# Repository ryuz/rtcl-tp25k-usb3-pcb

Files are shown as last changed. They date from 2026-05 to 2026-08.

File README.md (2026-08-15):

English version: [README_en.md](README_en.md)

# Tang Primer 25K 用 FT601 + MIPIコネクタ オリジナルベース基板

## 概要

Sipeed社の [Tang Primer 25K](https://wiki.sipeed.com/hardware/en/tang/tang-primer-25k/primer-25k.html) に搭載されている GW5A-LV25MG121 には MIPI D-PHY インターフェースが搭載されており、SoM までは配線が来ているようですが、残念ながら標準の Dock base board ではこのラインが未接続のままになっており、利用することができません。

本プロジェクトでは、MIPI D-PHY ラインを活用できるように 0.5mm ピッチ 22pin のコネクタに引き出したうえで、画像データなどを PC と交換できるように FT601 で USB3.0 接続できるオリジナルベース基板の設計データを提供します。

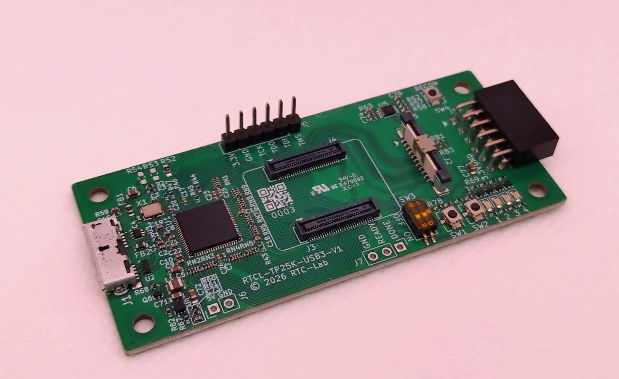
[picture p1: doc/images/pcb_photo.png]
pcb_photo


Tang Primer 25K の SoMボード でもともと使われていなかった MIPI ピンを利用するようにしていますが、特に MIPI を活用しなくとも、USB3.0 で FPGA を使えるようにしたボードとも言えますので、今まで FPGA と PC との接続で UART 程度で止まっていた人に本格的な FPGA 活用への第一歩として利用いただければ幸いです。

また、当方では試しておりませんが、GW5A-LV25MG121 の MIPI D-PHY は双方向ですので、MIPI-DSI など、表示系の実験にも利用できる可能性があります。

## スペック

主な実装内容は以下です。

- Tang-Primer25K-Core 取り付け用コネクタ
- FT601 による USB3.0 接続
- 4レーン MIPI コネクタ (22pin)
- PMOD コネクタ一個
- LED 4個
- プッシュスイッチ2個
- 2極ディップスイッチ
- JTAG 接続用 6pin ヘッダ

JTAG は外部に別途ダウンロードケーブルが必要ですが、[openFPGAloader](https://github.com/trabucayre/openFPGALoader)などを利用する場合は幅広いダウンロードケーブルが利用可能です。

また FT232HL などを利用する場合は、GOWIN EDA の GAO などを使ったデバッグも可能です。

## システムイメージ

### カメラ接続

[Raspberry PI V2 Camera](https://www.raspberrypi.com/documentation/accessories/camera.html) の接続例と、当方作の[RTCL-P3S7-MIPI](https://rtc-lab.com/products/rtcl-cam-p3s7-mipi/)の接続例です。

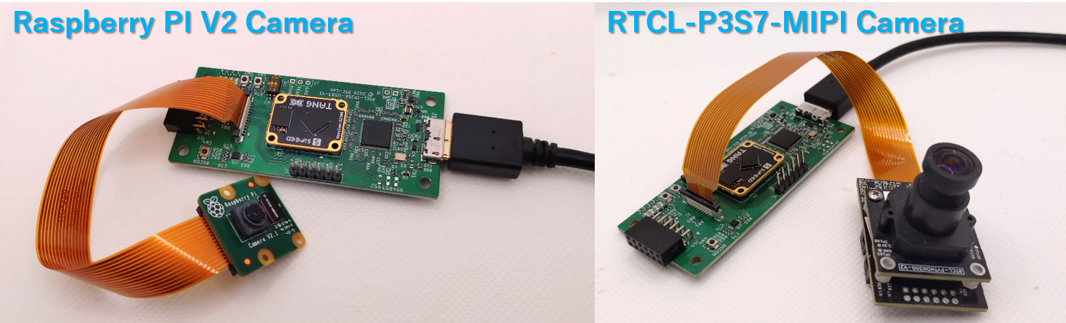
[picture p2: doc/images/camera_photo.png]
カメラ接続イメージ


### JTAG接続

Digilent社の [JTAG-HS２](https://digilent.com/reference/programmers/jtag-hs2/start) の接続例と、秋月電子の[FT232HL ハイスピードUSBシリアル変換モジュール](https://akizukidenshi.com/catalog/g/g106503/) の接続例です。

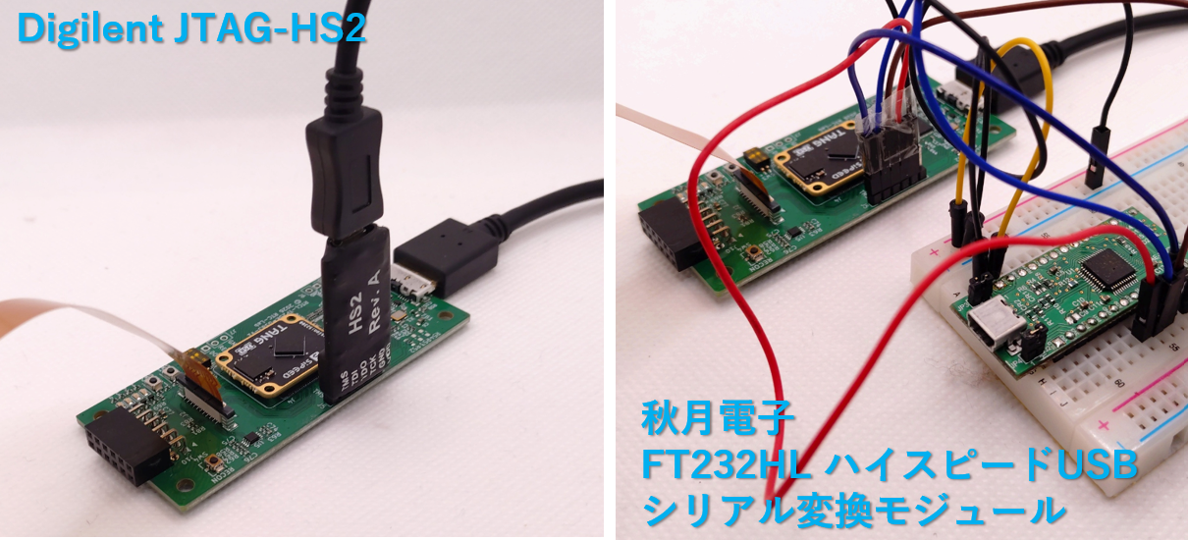
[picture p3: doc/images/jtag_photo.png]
JTAG接続イメージ


## 設計データ

### 回路図

回路図は以下です。

- [rtcl-tp25k-usb3_v2.pdf](rtcl-tp25k-usb3_v2.pdf)

### KiCAD 設計データ

rtcl-tp25k-usb3 ディレクトリ以下に KiCAD 10.0 で設計したデータを格納しています。

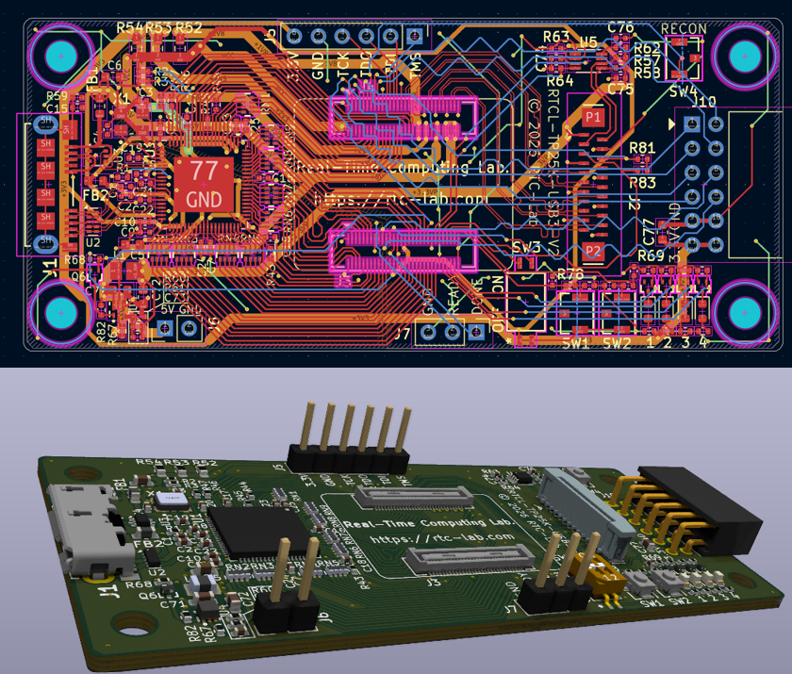
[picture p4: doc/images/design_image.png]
design_image


JLCPCB の `JLC04161H-3313` で製造する想定で設計しています。

### ソフトウェア

下記にて開発中です。

https://github.com/ryuz/rtcl-designs/tree/main/projects/rtcl_tp25k_usb3

## 基板販売

当方で製造したものを[BOOTH](https://rtc-lab.booth.pm/) 及び [BASE](https://rtcl.base.shop/) にて販売中です。

詳細は下記をご覧ください。

https://rtc-lab.com/products/rtcl-design-rtcl_tp25k_usb3/

## 免責事項

本設計データは、研究開発用の試作実験に供するものであり、利用に際して発生した如何なる損害も作者は補償いたしませんので予めご了承ください。

また設計データについてもなんら品質を保証するものではありません。

## ライセンス(License)

本設計データは、[クリエイティブ・コモンズ 表示-非営利 4.0 国際 ライセンス(CC BY-NC 4.0)](https://creativecommons.org/licenses/by-nc/4.0/deed.ja)の下で提供されています。

製造した本基板の無断での販売や配布を行わない限りは、趣味や研究開発用途でご自由にお使いいただく事が出来ます。

また、商用に製造販売を希望される場合は、別途ライセンス契約を作者までご相談ください。[お問い合わせフォーム](https://rtc-lab.com/contact/)などからお問い合わせ頂けます。

## 作者情報

渕上 竜司(Ryuji Fuchikami)
[リアルタイムコンピューティング研究所](https://rtc-lab.com/)

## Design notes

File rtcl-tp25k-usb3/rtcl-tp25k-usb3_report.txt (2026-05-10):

PCB 統計レポート
=====================
- 日付: 2026/05/10 14:33:20
- プロジェクト: rtcl-tp25k-usb3
- 基板名: rtcl-tp25k-usb3

基板
-----
- 幅: 80.0000 mm
- 高さ: 35.0000 mm
- 面積: 2800.00 mm²
- 表面導体面積: 554.94 mm²
- 裏面導体面積: 82.423 mm²
- 最小配線クリアランス: 0.1270 mm
- 最小配線幅: 0.1000 mm
- 最小ドリル直径: 0.3000 mm
- 基板スタックアップ厚さ: 1.6000 mm

- 表面フットプリント面積: 948.035 mm²
- 裏面フットプリント面積: 110.137 mm²
- 表面コンポーネント密度: 33.86 %
- 裏面コンポーネント密度: 3.93 %
パッド
----
- スルーホール: 18
- SMD: 470
- コネクタ: 0
- NPTH: 6
- 端面スルーホール: 0
- プレスフィット: 0

ビア
----
- 貫通ビア: 5
- ブラインド ビア: 0
- ベリード ビア: 0
- マイクロビア: 0

コンポーネント
----------

| | 表面 | 裏面 | 合計 |
|---|----|----|----|
|THT:  |  2 |  0 |  2 |
|SMD:  | 76 |  0 | 76 |
|不特定:  |  4 |  0 |  4 |
|合計: | 82 |  0 | 82 |

ドリル穴
-----------

| カウント | 形状 | X サイズ | Y サイズ |  メッキ | ビア/パッド | 開始レイヤー | 終了レイヤー |
|---|---|---|---|---|---|---|---|
| 18 | ラウンド | 1.0000 mm | 1.0000 mm |  PTH | パッド | F.Cu | B.Cu |
| 5 | ラウンド | 0.3000 mm | 0.3000 mm |  PTH | ビア | F.Cu | B.Cu |
| 4 | ラウンド | 3.2000 mm | 3.2000 mm | NPTH | パッド | F.Cu | B.Cu |
| 2 | スロット | 1.5001 mm | 0.8349 mm | NPTH | パッド | F.Cu | B.Cu |

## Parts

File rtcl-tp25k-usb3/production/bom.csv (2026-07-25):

Designator | Footprint | Quantity | Value | LCSC Part #
C1, C10, C11, C12, C15, C16, C17, C18, C19, C2, C20, C21, C22, C23, C24, C25, C7, C74, C75, C76, C8, C9 | 0402 | 22 | 0.1uF
C3, C4 | 0402 | 2 | 18pF
C5, C6, C71, C72, C77 | 0603 | 5 | 4.7uF
C73 | 0402 | 1 | 120pF | C40059
FB1, FB2 | 0603 | 2 | BLM18SG121TN1 | C113030
J1 | ZX360DB10P30 | 1 | ZX360D-B-10P(30) | C598201
J10 | PMOD_02x06_2.54mm | 1 | PMOD | C2897426
J2 | AFC11-S22ICA-00 | 1 | MIPI_22pin | C5248019
J3, J4 | CONN_DF40C-60DS_HIR | 2 | DF40C(2.0)-60DS-0.4V(51) | C3646124
J5 | PinHeader_1x06_P2.54mm_Vertical | 1 | JTAG | C6332199
J6 | PinHeader_1x02_P2.54mm_Vertical | 1 | Conn_01x02
J7 | PinHeader_1x03_P2.54mm_Vertical | 1 | Conn_01x03
L1 | INDC2016X100N | 1 | TFM201610ALM-R47MTAA | C501954
LED1, LED2, LED3, LED4 | 0603 | 4 | 150060VS55040 | C6390388
Q2, Q3, Q4, Q5, Q6 | SOT_34NT1G_ONS | 5 | NTK3134NT1G | C97777
R1 | 0402 | 1 | 1.6k_1%
R2, R3, R68, R69, R72, R74, R76, R77, R78, R79, R80, R81, R82, R83 | 0402 | 14 | 4.7k
R52 | 0603 | 1 | 0_1608 | C15402
R53, R54 | 0603 | 2 | <DNP>_R_1608
R57, R58, R63, R64 | 0402 | 4 | 2.2k
R59 | 0402 | 1 | 1M
R60 | 0402 | 1 | 22.6k_1%
R61 | 0402 | 1 | 100k_1%
R62 | 0402 | 1 | 200k
R67 | 0402 | 1 | 100k
R70, R71, R73, R75 | 0402 | 4 | 100
SW1, SW2, SW4 | B3U-1100P | 3 | B3U-1100P | C6467298
SW3 | 218-2LP_CTS | 1 | 218-2LPSTR | C2961921
U1 | QFN-76-1EP_9x9mm_P0.4mm_EP5.81x6.31mm | 1 | FT601Q | C1550513
U2 | USON-10_2.5x1.0mm_P0.5mm | 1 | TPD4E05U06DQA | C138714
U3 | SOT-666 | 1 | USBLC6-2P6 | C15999
U4 | DMQ0006A | 1 | TPS62826DMQR | C2073319
U5 | VSSOP-8_2.3x2mm_P0.5mm | 1 | PCA9306DCUR | C33196
X1 | XTAL_ABM8-30.000MHz-D1X-T | 1 | ABM8-30.000MHZ-D1X-T | C1986781

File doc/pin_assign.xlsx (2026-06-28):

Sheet: Sheet1
RTL | pin | SoMネット名 | FT601ネット名
ft601_clk | K5 | K5_IOT63B | FT601_CLK
ft601_txe_n | G2 | G2_IOR24A_40P | FT601_TXE
ft601_rxf_n | K4 | K4_IOR22B_40P | FT601_RXF
ft601_siwu_n | J4 | J4_IOR22A_40P | FT601_SIWU
ft601_wr_n | K2 | K2_IOR20B_40P | FT601_WR
ft601_rd_n | K1 | K1_IOR20A_40P | FT601_RD
ft601_oe_n | L1 | L1_IOR18B_40P | FT601_OE
ft601_gpio[0] | H1 | G1_IOR24B_40P | FT601_GPIO0
ft601_gpio[1] | H2 | L4_IOR31A_40P | FT601_GPIO1
ft601_be[0] | J1 | J1_IOR33A_40P | FT601_BE0
ft601_be[1] | L3 | L3_IOR31B_40P | FT601_BE1
ft601_be[2] | L4 | L4_IOR31A_40P | FT601_BE2
ft601_be[3] | G1 | G1_IOR24B_40P | FT601_BE3
ft601_data[0] | L11 | L11_IOT11B | FT601_D0
ft601_data[1] | K11 | K11_IOT11A | FT601_D1
ft601_data[2] | K10 | K10_IOT15B_40P | FT601_D2
ft601_data[3] | L10 | L10_IOT15A_40P | FT601_D3
ft601_data[4] | L8 | L8_IOT19B_40P | FT601_D4
ft601_data[5] | L7 | L7_IOT19A_40P | FT601_D5
ft601_data[6] | J7 | J7_IOT21B_40P | FT601_D6
ft601_data[7] | K7 | K7_IOT21A_40P | FT601_D7
ft601_data[8] | K6 | K6_IOT23B_USB_N | FT601_D8
ft601_data[9] | L6 | L6_IOT23A_USB_P | FT601_D9
ft601_data[10] | G5 | G5_IOT72B | FT601_D10
ft601_data[11] | F5 | F5_IOT72A | FT601_D11
ft601_data[12] | G8 | G8_IOT68B | FT601_D12
ft601_data[13] | G7 | G7_IOT68A | FT601_D13
ft601_data[14] | H7 | H7_IOT66B | FT601_D14
ft601_data[15] | H8 | H8_IOT66A | FT601_D15
ft601_data[16] | H5 | H5_IOT61A | FT601_D16
ft601_data[17] | J5 | J5_IOT61B | FT601_D17
ft601_data[18] | L5 | L5_IOT63A | FT601_D18
ft601_data[19] | L9 | L9_IOT31A_40P | FT601_D19
ft601_data[20] | K9 | K9_IOT31B_40P | FT601_D20
ft601_data[21] | J8 | J8_IOT56A_40P | FT601_D21
ft601_data[22] | K8 | K8_IOT56B_40P | FT601_D22
ft601_data[23] | F7 | F7_IOT58A_40P | FT601_D23
ft601_data[24] | F6 | F6_IOT58B_40P | FT601_D24
ft601_data[25] | J11 | J11_IOT1A_40P | FT601_D25
ft601_data[26] | J10 | J10_IOT1B_40P | FT601_D26
ft601_data[27] | H11 | H11_IOT3A_S1 | FT601_D27
ft601_data[28] | H10 | H10_IOT3B_S2 | FT601_D28
ft601_data[29] | G11 | G11_IOT7A | FT601_D29
ft601_data[30] | G4 | G4_IOB89A_40P | FT601_D30
ft601_data[31] | J2 | J2_IOR33B_40P | FT601_D31
ft601_reset_n | L2 | L2_IOR18A_40P | FT601_RESET
ft601_wakeup | H4 | H4_IOB89B_40P | FT601_WAKEUP

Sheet: Sheet2
No. | conn | pin | FPGA | NAME | bank | attr | Voltage | RTL | LOC
1 | J3 | 2 |  | GND | 0
12 | J3 | 24 |  | VCCIO0_1
13 | J3 | 26 |  | VCCIO0_1 |  |  |  |  |  | 1
14 | J3 | 28 |  | GND |  |  |  |  |  | 1
25 | J3 | 50 |  | GND |  |  |  |  |  | 1
30 | J3 | 60 |  | GND
31 | J3 | 1 |  | GND | 0 |  |  |  |  | 1
38 | J3 | 15 |  | GND |  |  |  |  |  | 1
44 | J3 | 27 |  | GND |  |  |  |  |  | 1
45 | J3 | 29 |  | VCCIO6_7 |  |  |  |  |  | 1
46 | J3 | 31 |  | VCCIO6_7 |  |  |  |  |  | 1
53 | J3 | 45 |  | GND |  |  |  |  |  | 1
60 | J3 | 59 |  | GND
61 | J4 | 2 |  | VCCIO2_3
62 | J4 | 4 |  | VCCIO2_3
79 | J4 | 38 |  | 1.8V |  |  |  |  |  | 1
80 | J4 | 40 |  | 1.8V |  |  |  |  |  | 1
81 | J4 | 42 |  | 2.5V |  |  |  |  |  | 1
82 | J4 | 44 |  | 2.5V |  |  |  |  |  | 1
83 | J4 | 46 |  | 3.3V |  |  |  |  |  | 1
84 | J4 | 48 |  | 3.3V |  |  |  |  |  | 1
85 | J4 | 50 |  | 3.3V |  |  |  |  |  | 1
86 | J4 | 52 |  | 5V |  |  |  |  |  | 1
87 | J4 | 54 |  | 5V |  |  |  |  |  | 1
88 | J4 | 56 |  | 5V |  |  |  |  |  | 1
89 | J4 | 58 |  | 5V
90 | J4 | 60 |  | 5V |  |  |  |  |  | 1
91 | J4 | 1 |  | GND |  |  |  |  |  | 1
97 | J4 | 13 | D8 | D8_RECONFIG | 5 |  | 3.3 |  |  | 1
100 | J4 | 19 |  | GND |  |  |  |  |  | 1
105 | J4 | 29 |  | GND
111 | J4 | 41 |  | GND
114 | J4 | 47 |  | GND |  |  |  |  |  | 1
117 | J4 | 53 |  | GND |  |  |  |  |  | 1
120 | J4 | 59 |  | GND |  |  |  |  |  | 1
56 | J3 | 51 | C11 | C11_IOL5A | 6 |  | 1.8 | dip_sw[0] | IO_LOC "dip_sw[0]" C11; | 1
57 | J3 | 53 | C10 | C10_IOL5B | 6 |  | 1.8 | dip_sw[1] | IO_LOC "dip_sw[1]" C10; | 1
73 | J4 | 26 | J1 | J1_IOR33A_40P | 2 | GCLK | 1.8 | ft601_be[0] | IO_LOC "ft601_be[0]" J1; | 1
72 | J4 | 24 | L3 | L3_IOR31B_40P | 2 | GCLK | 1.8 | ft601_be[1] | IO_LOC "ft601_be[1]" L3;
71 | J4 | 22 | L4 | L4_IOR31A_40P | 2 | GCLK | 1.8 | ft601_be[2] | IO_LOC "ft601_be[2]" L4;
70 | J4 | 20 | G1 | G1_IOR24B_40P | 2 |  | 1.8 | ft601_be[3] | IO_LOC "ft601_be[3]" G1; | 1
5 | J3 | 10 | K5 | K5_IOT63B | 0 | GCLK | 1.8 | ft601_clk | IO_LOC "ft601_clk" K5; | 1
24 | J3 | 48 | L11 | L11_IOT11B | 7 |  | 1.8 | ft601_data[0] | IO_LOC "ft601_data[0]" L11;
23 | J3 | 46 | K11 | K11_IOT11A | 7 |  | 1.8 | ft601_data[1] | IO_LOC "ft601_data[1]" K11;
11 | J3 | 22 | G5 | G5_IOT72B | 0 |  | 1.8 | ft601_data[10] | IO_LOC "ft601_data[10]" G5;
10 | J3 | 20 | F5 | F5_IOT72A | 0 |  | 1.8 | ft601_data[11] | IO_LOC "ft601_data[11]" F5;
9 | J3 | 18 | G8 | G8_IOT68B | 0 |  | 1.8 | ft601_data[12] | IO_LOC "ft601_data[12]" G8;
8 | J3 | 16 | G7 | G7_IOT68A | 0 |  | 1.8 | ft601_data[13] | IO_LOC "ft601_data[13]" G7; | 1
7 | J3 | 14 | H7 | H7_IOT66B | 0 |  | 1.8 | ft601_data[14] | IO_LOC "ft601_data[14]" H7; | 1
6 | J3 | 12 | H8 | H8_IOT66A | 0 |  | 1.8 | ft601_data[15] | IO_LOC "ft601_data[15]" H8; | 1
2 | J3 | 4 | H5 | H5_IOT61A | 0 | GCLK | 1.8 | ft601_data[16] | IO_LOC "ft601_data[16]" H5; | 1
3 | J3 | 6 | J5 | J5_IOT61B | 0 | GCLK | 1.8 | ft601_data[17] | IO_LOC "ft601_data[17]" J5; | 1
4 | J3 | 8 | L5 | L5_IOT63A | 0 | GCLK | 1.8 | ft601_data[18] | IO_LOC "ft601_data[18]" L5;
32 | J3 | 3 | L9 | L9_IOT31A_40P | 0 |  | 1.8 | ft601_data[19] | IO_LOC "ft601_data[19]" L9;
22 | J3 | 44 | K10 | K10_IOT15B_40P | 7 |  | 1.8 | ft601_data[2] | IO_LOC "ft601_data[2]" K10;
33 | J3 | 5 | K9 | K9_IOT31B_40P | 0 |  | 1.8 | ft601_data[20] | IO_LOC "ft601_data[20]" K9;
34 | J3 | 7 | J8 | J8_IOT56A_40P | 0 | GCLK | 1.8 | ft601_data[21] | IO_LOC "ft601_data[21]" J8;
35 | J3 | 9 | K8 | K8_IOT56B_40P | 0 | GCLK | 1.8 | ft601_data[22] | IO_LOC "ft601_data[22]" K8;
36 | J3 | 11 | F7 | F7_IOT58A_40P | 0 | GCLK | 1.8 | ft601_data[23] | IO_LOC "ft601_data[23]" F7;
37 | J3 | 13 | F6 | F6_IOT58B_40P |  | GCLK | 1.8 | ft601_data[24] | IO_LOC "ft601_data[24]" F6;
47 | J3 | 33 | J11 | J11_IOT1A_40P | 7 | GCLK | 1.8 | ft601_data[25] | IO_LOC "ft601_data[25]" J11;
48 | J3 | 35 | J10 | J10_IOT1B_40P | 7 | GCLK | 1.8 | ft601_data[26] | IO_LOC "ft601_data[26]" J10;
49 | J3 | 37 | H11 | H11_IOT3A_S1 | 7 | GCLK | 1.8 | ft601_data[27] | IO_LOC "ft601_data[27]" H11;
50 | J3 | 39 | H10 | H10_IOT3B_S2 | 7 | GCLK | 1.8 | ft601_data[28] | IO_LOC "ft601_data[28]" H10; | 1
51 | J3 | 41 | G11 | G11_IOT7A | 7 |  | 1.8 | ft601_data[29] | IO_LOC "ft601_data[29]" G11; | 1
21 | J3 | 42 | L10 | L10_IOT15A_40P | 7 |  | 1.8 | ft601_data[3] | IO_LOC "ft601_data[3]" L10; | 1
75 | J4 | 30 | G4 | G4_IOB89A_40P | 3 | GCLK | 1.8 | ft601_data[30] | IO_LOC "ft601_data[30]" G4; | 1
74 | J4 | 28 | J2 | J2_IOR33B_40P | 2 | GCLK | 1.8 | ft601_data[31] | IO_LOC "ft601_data[31]" J2; | 1
20 | J3 | 40 | L8 | L8_IOT19B_40P | 7 |  | 1.8 | ft601_data[4] | IO_LOC "ft601_data[4]" L8; | 1
19 | J3 | 38 | L7 | L7_IOT19A_40P | 7 |  | 1.8 | ft601_data[5] | IO_LOC "ft601_data[5]" L7; | 1
18 | J3 | 36 | J7 | J7_IOT21B_40P | 7 |  | 1.8 | ft601_data[6] | IO_LOC "ft601_data[6]" J7; | 1
17 | J3 | 34 | K7 | K7_IOT21A_40P | 7 |  | 1.8 | ft601_data[7] | IO_LOC "ft601_data[7]" K7; | 1
16 | J3 | 32 | K6 | K6_IOT23B_USB_N | 7 |  | 1.8 | ft601_data[8] | IO_LOC "ft601_data[8]" K6; | 1
15 | J3 | 30 | L6 | L6_IOT23A_USB_P | 7 |  | 1.8 | ft601_data[9] | IO_LOC "ft601_data[9]" L6; | 1
77 | J4 | 34 | H1 | H1_IOB91A_40P | 3 | GCLK | 1.8 | ft601_gpio[0] | IO_LOC "ft601_gpio[0]" H1; | 1
78 | J4 | 36 | H2 | H2_IOB91B_40P | 3 | GCLK | 1.8 | ft601_gpio[1] | IO_LOC "ft601_gpio[1]" H2; | 1
64 | J4 | 8 | L1 | L1_IOR18B_40P | 2 |  | 1.8 | ft601_oe_n | IO_LOC "ft601_oe_n" L1; | 1
65 | J4 | 10 | K1 | K1_IOR20A_40P | 2 |  | 1.8 | ft601_rd_n | IO_LOC "ft601_rd_n" K1; | 1
63 | J4 | 6 | L2 | L2_IOR18A_40P | 2 |  | 1.8 | ft601_reset_n | IO_LOC "ft601_reset_n" L2; | 1
68 | J4 | 16 | K4 | K4_IOR22B_40P | 2 |  | 1.8 | ft601_rxf_n | IO_LOC "ft601_rxf_n" K4;
67 | J4 | 14 | J4 | J4_IOR22A_40P | 2 |  | 1.8 | ft601_siwu_n | IO_LOC "ft601_siwu_n" J4;
69 | J4 | 18 | G2 | G2_IOR24A_40P | 2 | RPLL | 1.8 | ft601_txe_n | IO_LOC "ft601_txe_n" G2;
76 | J4 | 32 | H4 | H4_IOB89B_40P | 3 | GCLK | 1.8 | ft601_wakeup | IO_LOC "ft601_wakeup" H4;
66 | J4 | 12 | K2 | K2_IOR20B_40P | 2 |  | 1.8 | ft601_wr_n | IO_LOC "ft601_wr_n" K2;
0 |  |  | E2 | IOB12A | 5 |  | 3.3 | in_clk50 | IO_LOC "in_clk50" E2;
101 | J4 | 21 | C1 | C1_JTAG_TCK | 10 |  | 3.3 | JTAG | IO_LOC "JTAG" C1;
102 | J4 | 23 | B1 | B1_JTAG_TMS | 10 |  | 3.3 | JTAG | IO_LOC "JTAG" B1;
103 | J4 | 25 | A2 | A2_JTAG_TDO | 10 |  | 3.3 | JTAG | IO_LOC "JTAG" A2;
104 | J4 | 27 | A3 | A3_JTAG_TDI | 10 |  | 3.3 | JTAG | IO_LOC "JTAG" A3;
29 | J3 | 58 | A10 | A10_IOL14B | 6 |  |  | led[0] | IO_LOC "led[0]" A10;
28 | J3 | 56 | A11 | A11_IOL14A | 6 |  |  | led[1] | IO_LOC "led[1]" A11;
27 | J3 | 54 | E10 | E10_IOL3B | 6 |  |  | led[2] | IO_LOC "led[2]" E10;
26 | J3 | 52 | E11 | E11_IOL3A | 6 |  |  | led[3] | IO_LOC "led[3]" E11; | 1
113 | J4 | 45 | B7 | M0_CK_N |  |  |  | mipi_ck_n | IO_LOC "mipi_ck_n" B7; | 1
112 | J4 | 43 | A7 | M0_CK_P |  |  |  | mipi_ck_p | IO_LOC "mipi_ck_p" A7; | 1
116 | J4 | 51 | B8 | M0_D1_N |  |  |  | mipi_d_n[1] | IO_LOC "mipi_d_n[1]" B8; | 1
119 | J4 | 57 | B9 | M0_D0_N |  |  |  | mipi_d_n[0] | IO_LOC "mipi_d_n[0]" B9;
110 | J4 | 39 | B6 | M0_D2_N |  |  |  | mipi_d_n[2] | IO_LOC "mipi_d_n[2]" B6;
107 | J4 | 33 | B5 | M0_D3_N |  |  |  | mipi_d_n[3] | IO_LOC "mipi_d_n[3]" B5; | 1
115 | J4 | 49 | A8 | M0_D1_P |  |  |  | mipi_d_p[1] | IO_LOC "mipi_d_p[1]" A8; | 1
118 | J4 | 55 | A9 | M0_D0_P |  |  |  | mipi_d_p[0] | IO_LOC "mipi_d_p[0]" A9;
109 | J4 | 37 | A6 | M0_D2_P |  |  |  | mipi_d_p[2] | IO_LOC "mipi_d_p[2]" A6;
106 | J4 | 31 | A5 | M0_D3_P |  |  |  | mipi_d_p[3] | IO_LOC "mipi_d_p[3]" A5;
96 | J4 | 11 | A1 | A1_IOB24A_40P | 5 |  | 3.3 | mipi_gpio[0] | IO_LOC "mipi_gpio[0]" A1;
42 | J3 | 23 | E3 | E3_IOB60A_40P | 4 |  | 3.3 | mipi_gpio[1] | IO_LOC "mipi_gpio[1]" E3;
52 | J3 | 43 | G10 | G10_IOT7B | 7 |  | 1.8 | mipi_pwr_en_n | IO_LOC "mipi_pwr_en_n" G10;
54 | J3 | 47 | D11 | D11_IOL9A | 6 |  | 1.8 | mipi_scl | IO_LOC "mipi_scl" D11;
55 | J3 | 49 | D10 | D10_IOL9B | 6 |  | 1.8 | mipi_sda | IO_LOC "mipi_sda" D10;
94 | J4 | 7 | F2 | F2_IOB26A_40P | 5 | GCLK | 3.3 | pmod[0] | IO_LOC "pmod[0]" F2;
95 | J4 | 9 | F1 | F1_IOB26B_40P | 5 | GCLK | 3.3 | pmod[1] | IO_LOC "pmod[1]" F1;
92 | J4 | 3 | B2 | B2_IOB4A_40P | 5 |  | 3.3 | pmod[2] | IO_LOC "pmod[2]" B2;
93 | J4 | 5 | C2 | C2_IOB4B_40P | 5 |  | 3.3 | pmod[3] | IO_LOC "pmod[3]" C2;
98 | J4 | 15 | E1 | E1_IOB12B_40P | 5 | GCLK | 3.3 | pmod[4] | IO_LOC "pmod[4]" E1;
99 | J4 | 17 | D1 | D1_IOB14B_40P | 5 |  | 3.3 | pmod[5] | IO_LOC "pmod[5]" D1;
40 | J3 | 19 | B3 | B3_IOB56A_UART_RX | 4 |  | 3.3 | pmod[6] | IO_LOC "pmod[6]" B3;
41 | J3 | 21 | C3 | C3_IOB56B_UART_TX | 4 |  | 3.3 | pmod[7] | IO_LOC "pmod[7]" C3;
59 | J3 | 57 | B10 | B10_IOL12B | 6 |  | 1.8 | push_sw[0] | IO_LOC "push_sw[0]" B10;
58 | J3 | 55 | B11 | B11_IOL12A | 6 |  | 1.8 | push_sw[1] | IO_LOC "push_sw[1]" B11;
39 | J3 | 17 | E8 | E8_READY | 4 |  | 3.3 | test[0] | IO_LOC "test[0]" E8;
43 | J3 | 25 | D7 | D7_DONE | 4 |  | 3.3 | test[1] | IO_LOC "test[1]" D7;
108 | J4 | 35 |  | GND

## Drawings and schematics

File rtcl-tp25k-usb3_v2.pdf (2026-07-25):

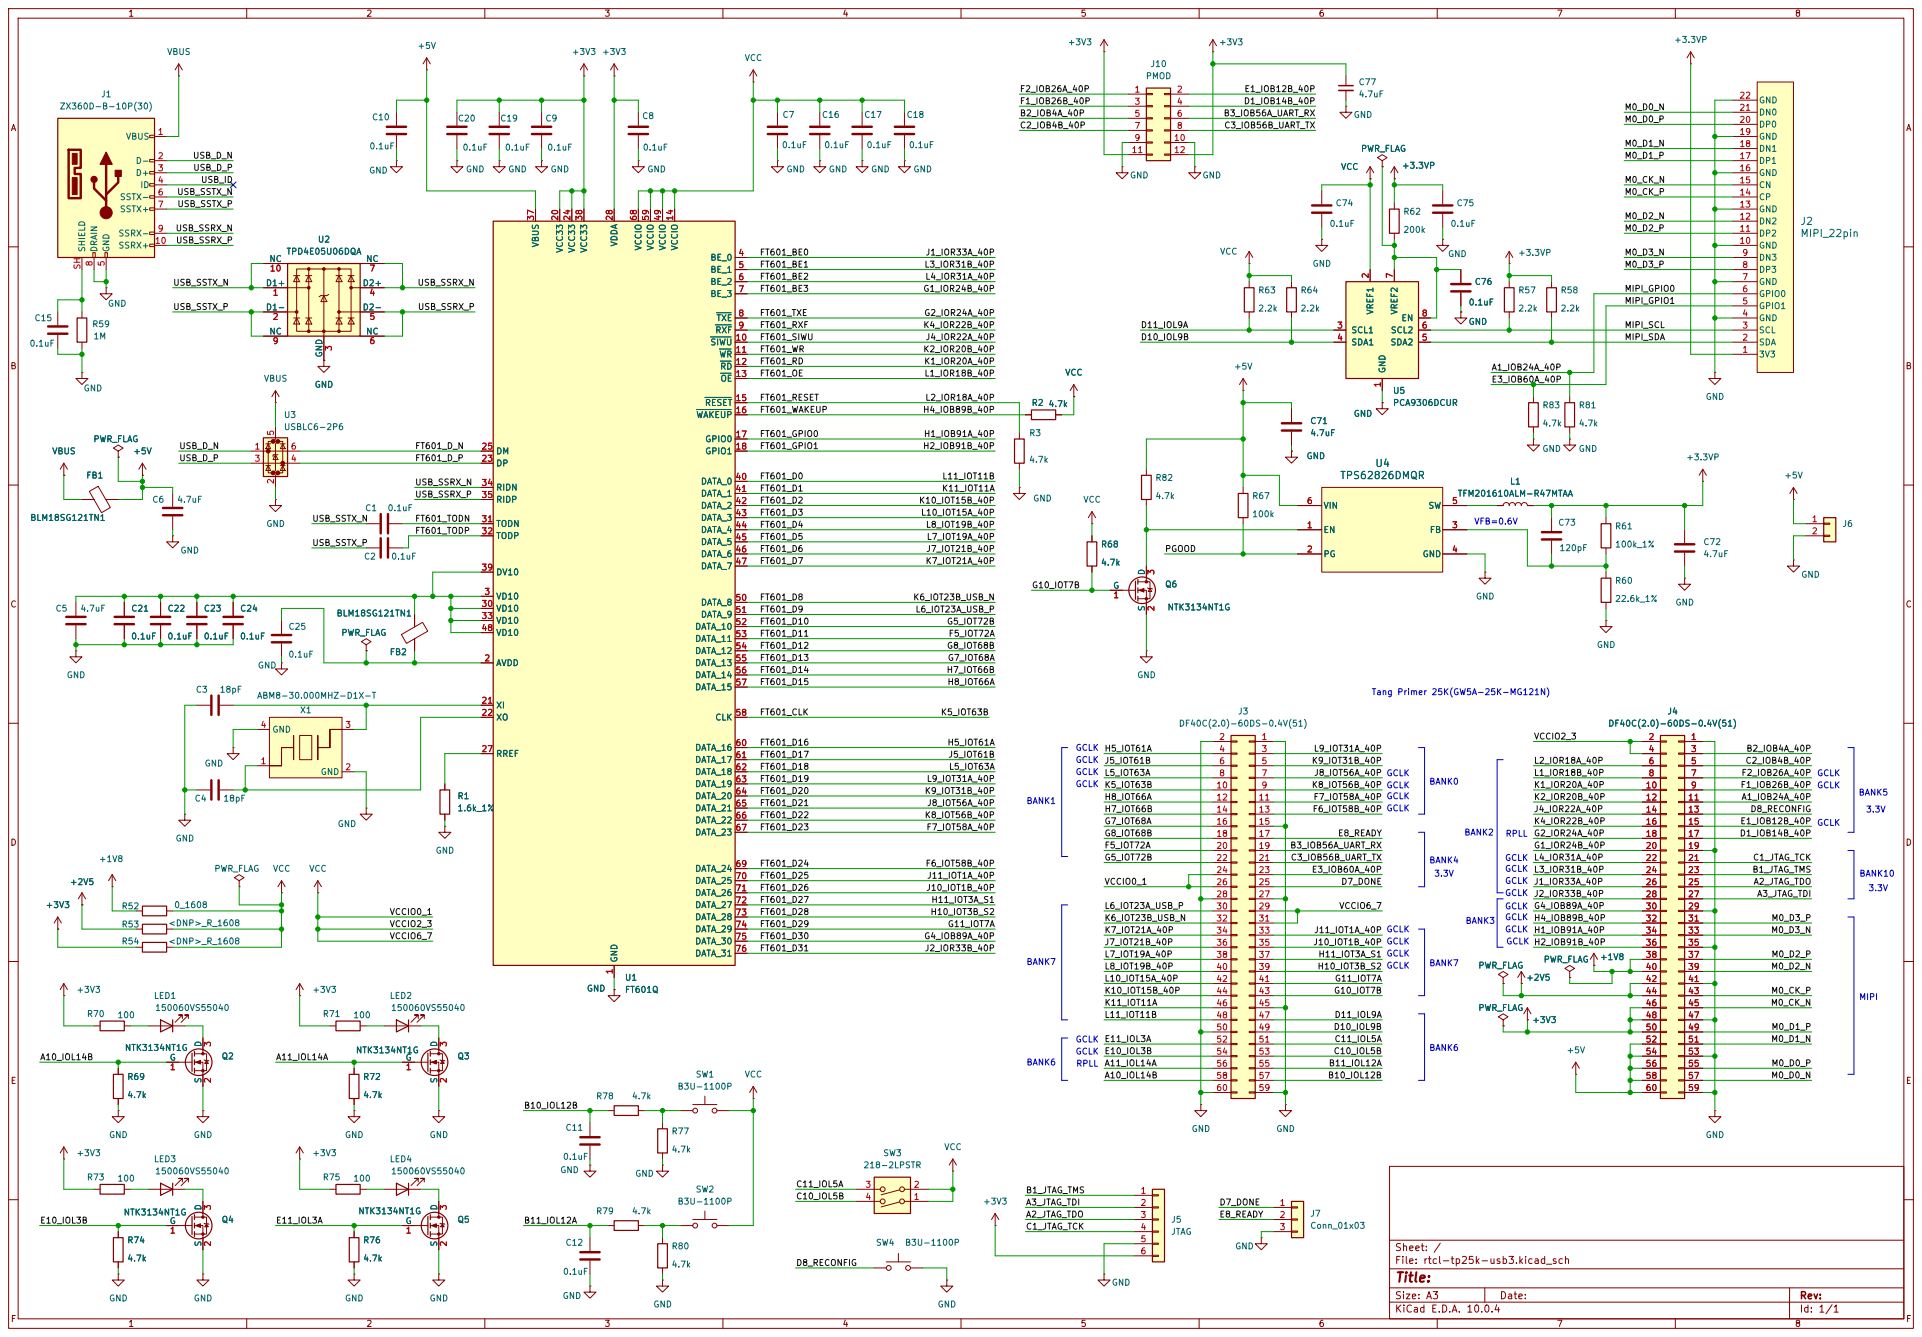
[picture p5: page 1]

D1+ | 6NC 6NC 4 D2-4 D2-
7 NC

Size: A3 | Rev:
KiCad E.D.A. 10.0.4 | Id: 1/1 | F Date:

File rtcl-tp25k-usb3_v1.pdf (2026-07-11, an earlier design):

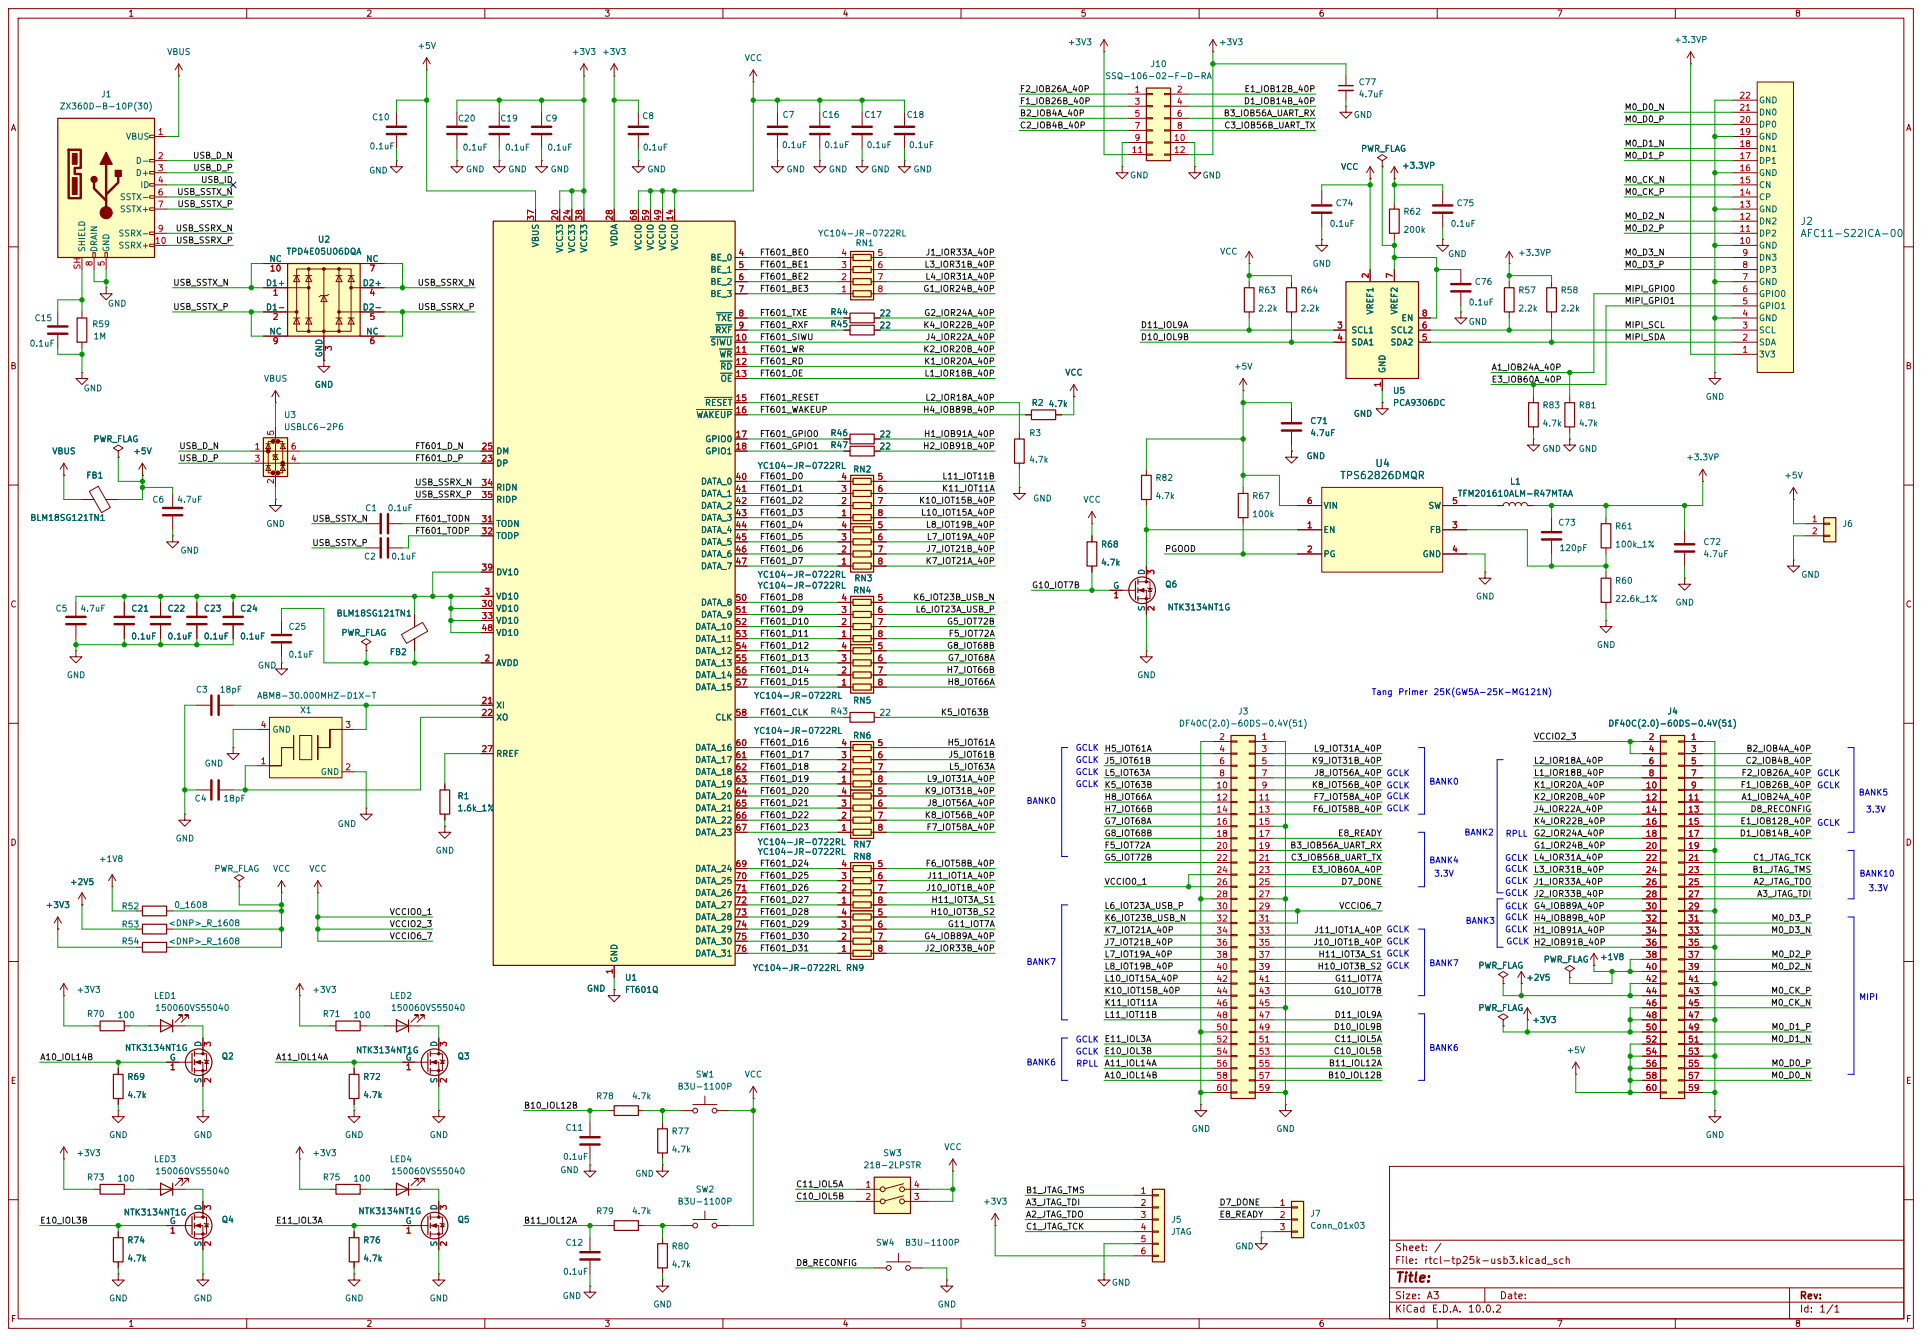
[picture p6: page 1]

ID SSTX+ SSRX+ | 4 GND 7 DRAIN 10 SHIELD SH

FT601_D6 2 2 | 7 7 J7_IOT21B_40P
FT601_D7 1 | K7_IOT21A_40P

FT601_D10 2 2 | 7 7 G5_IOT72B
FT601_D11 1 | F5_IOT72A
FT601_D12 4 4 | 5 5 G8_IOT68B

FT601_D21 3 3 | J3 DF40C(2.0)-60DS-0.4V(51) LED2 6 6 J8_IOT56A_40P

FT601_D17 3 3 | 6 6 J5_IOT61B
FT601_D18 2 2 | 7 7

FT601_D19 | L5_IOT63A K9_IOT31B_40P 8

FT601_D22 2 2 | 7 7 K8_IOT56B_40P

1 1 | 8 F7_IOT58A_40P

FT601_D27 1 | H11_IOT3A_S1 8
FT601_D28 4 4 | 5 5 G11_IOT7A H10_IOT3B_S2

VCCIO2_3 | FT601_D29 3 3 | 6 6

FT601_D30 2 2 | 7 7 G4_IOB89A_40P
FT601_D31 1 1 | 8 J2_IOR33B_40P

Size: A3 | Rev:
KiCad E.D.A. 10.0.2 | Id: 1/1 | F Date:

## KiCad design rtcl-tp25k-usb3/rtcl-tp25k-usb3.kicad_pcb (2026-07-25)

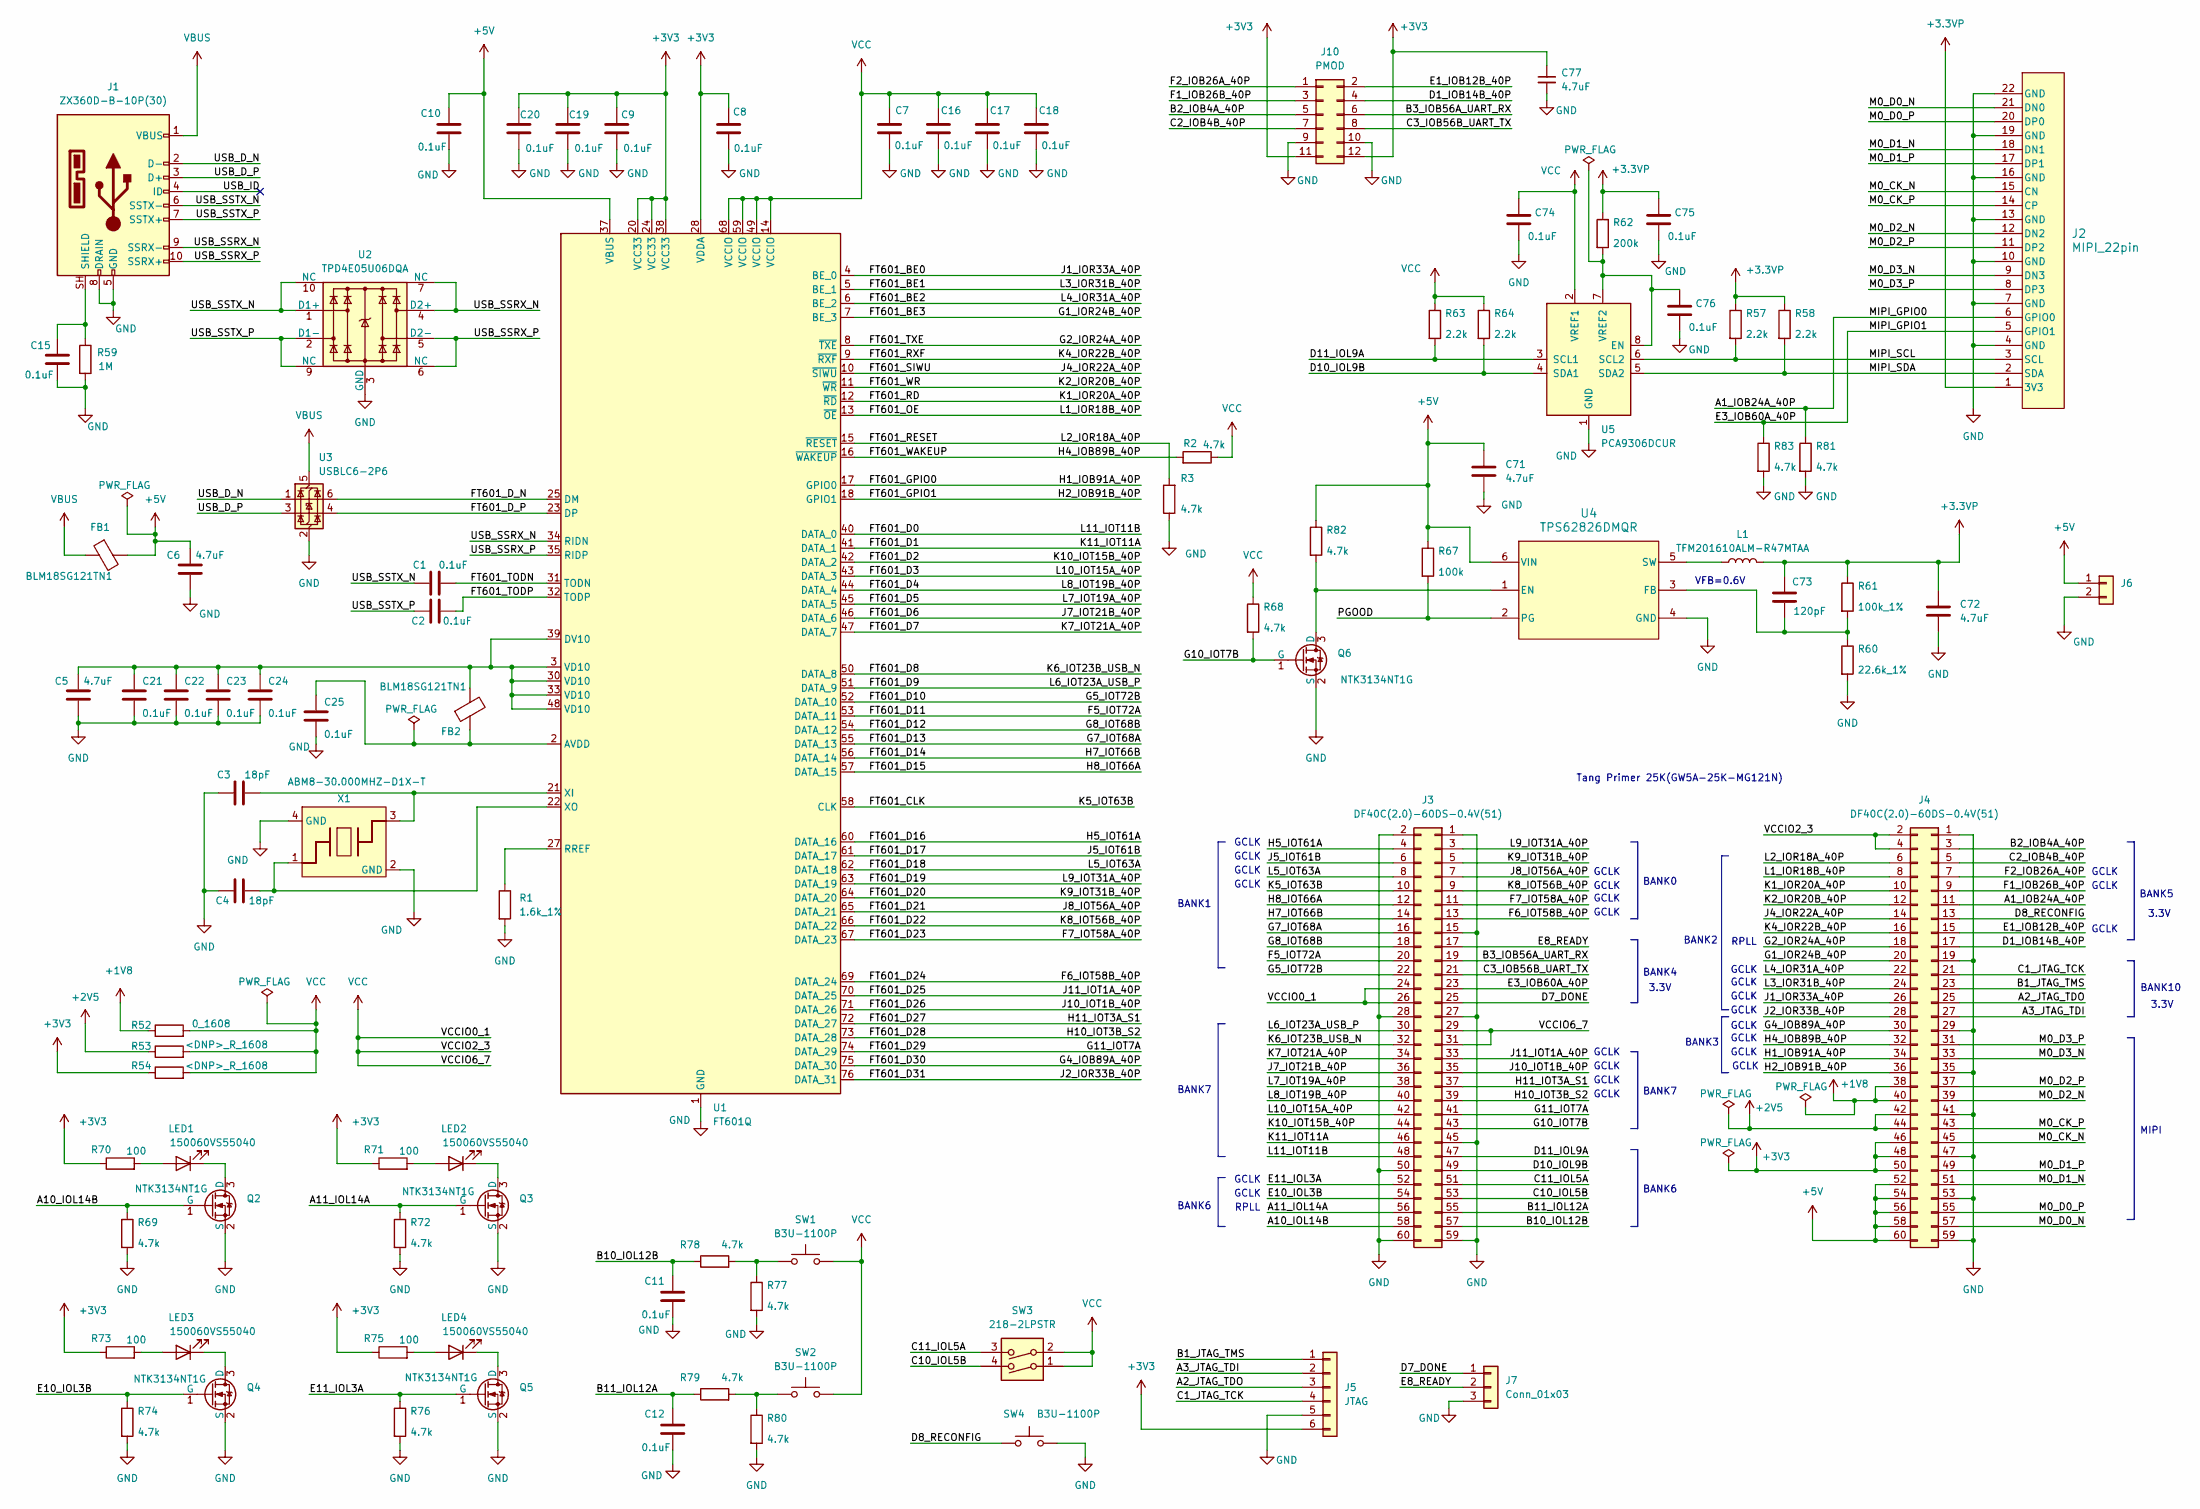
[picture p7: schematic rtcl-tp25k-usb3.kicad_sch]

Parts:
C1, C2, C7, C8, C9, C10, C11, C12, C15, C16, C17, C18, C19, C20, C21, C22, C23, C24, C25, C74, C75, C76: 0.1uF; C_0402_1005Metric
C3, C4: 18pF; C_0402_1005Metric
C5, C6, C71, C72, C77: 4.7uF; C_0603_1608Metric
C73: 120pF; C_0402_1005Metric; LCSC C40059
FB1, FB2: BLM18SG121TN1; L_0603_1608Metric; LCSC C113030
J1: ZX360D-B-10P(30); ZX360DB10P30; LCSC C598201
J2: MIPI_22pin; AFC11-S22ICA-00; LCSC C5248019
J3, J4: DF40C(2.0)-60DS-0.4V(51); CONN_DF40C-60DS_HIR; LCSC C3646124
J5: JTAG; PinHeader_1x06_P2.54mm_Vertical; LCSC C6332199
J6: Conn_01x02; PinHeader_1x02_P2.54mm_Vertical
J7: Conn_01x03; PinHeader_1x03_P2.54mm_Vertical
J10: PMOD; PMOD_02x06_2.54mm; LCSC C2897426
L1: TFM201610ALM-R47MTAA; INDC2016X100N; LCSC C501954
LED1, LED2, LED3, LED4: 150060VS55040; LED_0603_1608Metric; LCSC C6390388
Q2, Q3, Q4, Q5, Q6: NTK3134NT1G; SOT_34NT1G_ONS; Part 2SK3018; LCSC C97777
R1: 1.6k_1%; R_0402_1005Metric
R2, R3, R68, R69, R72, R74, R76, R77, R78, R79, R80, R81, R82, R83: 4.7k; R_0402_1005Metric
R52: 0_1608; R_0603_1608Metric_Pad0.98x0.95mm_HandSolder; LCSC C15402
R53, R54: <DNP>_R_1608; R_0603_1608Metric_Pad0.98x0.95mm_HandSolder
R57, R58, R63, R64: 2.2k; R_0402_1005Metric
R59: 1M; R_0402_1005Metric
R60: 22.6k_1%; R_0402_1005Metric
R61: 100k_1%; R_0402_1005Metric
R62: 200k; R_0402_1005Metric
R67: 100k; R_0402_1005Metric
R70, R71, R73, R75: 100; R_0402_1005Metric
SW1, SW2, SW4: B3U-1100P; LCSC C6467298
SW3: 218-2LPSTR; 218-2LP_CTS; LCSC C2961921
U1: FT601Q; QFN-76-1EP_9x9mm_P0.4mm_EP5.81x6.31mm; LCSC C1550513
U2: TPD4E05U06DQA; USON-10_2.5x1.0mm_P0.5mm; LCSC C138714
U3: USBLC6-2P6; SOT-666; LCSC C15999
U4: TPS62826DMQR; DMQ0006A; LCSC C2073319
U5: PCA9306DCUR; VSSOP-8_2.3x2mm_P0.5mm; LCSC C33196
X1: ABM8-30.000MHZ-D1X-T; XTAL_ABM8-30.000MHz-D1X-T; LCSC C1986781

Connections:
+1V8: J4.38, J4.40, R52.1
+2V5: J4.42, J4.44, R53.1
+3.3VP: C72.1, C73.1, C75.1, J2.1 (3V3), L1.2, R57.1, R58.1, R61.1, R62.1
+3V3: C8.2, C9.2, C19.2, C20.2, C77.1, J4.46, J4.48, J4.50, J5.6, J10.11, J10.12, R54.1, R70.1, R71.1, R73.1, R75.1, U1.20 (VCC33), U1.24 (VCC33), U1.28 (VDDA), U1.38 (VCC33)
+5V: C6.2, C10.2, C71.1, FB1.2, J4.52, J4.54, J4.56, J4.58, J4.60, J6.1, R67.1, R82.1, U1.37 (VBUS), U4.6 (VIN)
/A1_IOB24A_40P: J2.6 (GPIO0), J4.11, R81.1
/A2_JTAG_TDO: J4.25, J5.3
/A3_JTAG_TDI: J4.27, J5.2
/A10_IOL14B: J3.58, Q2.1 (G), R69.1
/A11_IOL14A: J3.56, Q3.1 (G), R72.1
/B1_JTAG_TMS: J4.23, J5.1
/B2_IOB4A_40P: J4.3, J10.5
/B3_IOB56A_UART_RX: J3.19, J10.6
/B10_IOL12B: C11.2, J3.57, R78.1
/B11_IOL12A: C12.2, J3.55, R79.1
/C1_JTAG_TCK: J4.21, J5.4
/C2_IOB4B_40P: J4.5, J10.7
/C3_IOB56B_UART_TX: J3.21, J10.8
/C10_IOL5B: J3.53, SW3.4
/C11_IOL5A: J3.51, SW3.3
/D1_IOB14B_40P: J4.17, J10.4
/D7_DONE: J3.25, J7.1
/D8_RECONFIG: J4.13, SW4.1
/D10_IOL9B: J3.49, R64.2, U5.4 (SDA1)
/D11_IOL9A: J3.47, R63.2, U5.3 (SCL1)
/E1_IOB12B_40P: J4.15, J10.2
/E3_IOB60A_40P: J2.5 (GPIO1), J3.23, R83.1
/E8_READY: J3.17, J7.2
/E10_IOL3B: J3.54, Q4.1 (G), R74.1
/E11_IOL3A: J3.52, Q5.1 (G), R76.1
/F1_IOB26B_40P: J4.9, J10.3
/F2_IOB26A_40P: J4.7, J10.1
/F5_IOT72A: J3.20, U1.53 (DATA_11)
/F6_IOT58B_40P: J3.13, U1.69 (DATA_24)
/F7_IOT58A_40P: J3.11, U1.67 (DATA_23)
/FT601_BE0: J4.26, U1.4 (BE_0)
/FT601_BE1: J4.24, U1.5 (BE_1)
/FT601_BE2: J4.22, U1.6 (BE_2)
/FT601_BE3: J4.20, U1.7 (BE_3)
/FT601_CLK: J3.10, U1.58 (CLK)
/FT601_D0: J3.48, U1.40 (DATA_0)
/FT601_D1: J3.46, U1.41 (DATA_1)
/FT601_D2: J3.44, U1.42 (DATA_2)
/FT601_D3: J3.42, U1.43 (DATA_3)
/FT601_D4: J3.40, U1.44 (DATA_4)
/FT601_D5: J3.38, U1.45 (DATA_5)
/FT601_D6: J3.36, U1.46 (DATA_6)
/FT601_D7: J3.34, U1.47 (DATA_7)
/FT601_D8: J3.32, U1.50 (DATA_8)
/FT601_D9: J3.30, U1.51 (DATA_9)
/FT601_D10: J3.22, U1.52 (DATA_10)
/FT601_D12: J3.18, U1.54 (DATA_12)
/FT601_D13: J3.16, U1.55 (DATA_13)
/FT601_D14: J3.14, U1.56 (DATA_14)
/FT601_D15: J3.12, U1.57 (DATA_15)
/FT601_D16: J3.4, U1.60 (DATA_16)
/FT601_D17: J3.6, U1.61 (DATA_17)
/FT601_D18: J3.8, U1.62 (DATA_18)
/FT601_D19: J3.3, U1.63 (DATA_19)
/FT601_D20: J3.5, U1.64 (DATA_20)
/FT601_D21: J3.7, U1.65 (DATA_21)
/FT601_D22: J3.9, U1.66 (DATA_22)
/FT601_D25: J3.33, U1.70 (DATA_25)
/FT601_D26: J3.35, U1.71 (DATA_26)
/FT601_D27: J3.37, U1.72 (DATA_27)
/FT601_D28: J3.39, U1.73 (DATA_28)
/FT601_D29: J3.41, U1.74 (DATA_29)
/FT601_D30: J4.30, U1.75 (DATA_30)
/FT601_D31: J4.28, U1.76 (DATA_31)
/FT601_D_N: U1.25 (DM), U3.6 (I/O1)
/FT601_D_P: U1.23 (DP), U3.4 (I/O2)
/FT601_GPIO0: J4.34, U1.17 (GPIO0)
/FT601_GPIO1: J4.36, U1.18 (GPIO1)
/FT601_OE: J4.8, U1.13 (~OE)
/FT601_RD: J4.10, U1.12 (~RD)
/FT601_RESET: J4.6, R3.2, U1.15 (~RESET)
/FT601_RXF: J4.16, U1.9 (~RXF)
/FT601_SIWU: J4.14, U1.10 (~SIWU)
/FT601_TODN: C1.2, U1.31 (TODN)
/FT601_TODP: C2.2, U1.32 (TODP)
/FT601_TXE: J4.18, U1.8 (~TXE)
/FT601_WAKEUP: J4.32, R2.2, U1.16 (~WAKEUP)
/FT601_WR: J4.12, U1.11 (~WR)
/G10_IOT7B: J3.43, Q6.1 (G), R68.2
/M0_CK_N: J2.15 (CN), J4.45
/M0_CK_P: J2.14 (CP), J4.43
/M0_D0_N: J2.21 (DN0), J4.57
/M0_D0_P: J2.20 (DP0), J4.55
/M0_D1_N: J2.18 (DN1), J4.51
/M0_D1_P: J2.17 (DP1), J4.49
/M0_D2_N: J2.12 (DN2), J4.39
/M0_D2_P: J2.11 (DP2), J4.37
/M0_D3_N: J2.9 (DN3), J4.33
/M0_D3_P: J2.8 (DP3), J4.31
/MIPI_SCL: J2.3 (SCL), R57.2, U5.6 (SCL2)
/MIPI_SDA: J2.2 (SDA), R58.2, U5.5 (SDA2)
/PGOOD: R67.2, U4.2 (PG)
/USB_D_N: J1.2 (D-), U3.1 (I/O1)
/USB_D_P: J1.3 (D+), U3.3 (I/O2)
/USB_ID: J1.4 (ID)
/USB_SSRX_N: J1.9 (SSRX-), U1.34 (RIDN), U2.4 (D2+), U2.7 (NC)
/USB_SSRX_P: J1.10 (SSRX+), U1.35 (RIDP), U2.5 (D2-), U2.6 (NC)
/USB_SSTX_N: C1.1, J1.6 (SSTX-), U2.1 (D1+), U2.10 (NC)
/USB_SSTX_P: C2.1, J1.7 (SSTX+), U2.2 (D1-), U2.9 (NC)
GND: C3.1, C4.1, C5.1, C6.1, C7.1, C8.1, C9.1, C10.1, C11.1, C12.1, C15.1, C16.1, C17.1, C18.1, C19.1, C20.1, C21.1, C22.1, C23.1, C24.1, C25.1, C71.2, C72.2, C74.2, C75.2, C76.2, C77.2, J1.5 (GND), J1.8 (DRAIN), J2.4 (GND), J2.7 (GND), J2.10 (GND), J2.13 (GND), J2.16 (GND), J2.19 (GND), J2.22 (GND), J3.1, J3.2, J3.15, J3.27, J3.28, J3.45, J3.50, J3.59, J3.60, J4.1, J4.19, J4.29, J4.35, J4.41, J4.47, J4.53, J4.59, J5.5, J6.2, J7.3, J10.9, J10.10, Q2.2 (S), Q3.2 (S), Q4.2 (S), Q5.2 (S), Q6.2 (S), R1.2, R3.1, R59.2, R60.2, R69.2, R72.2, R74.2, R76.2, R77.2, R80.2, R81.2, R83.2, SW4.2, U1.1 (GND), U1.26 (GND), U1.29 (GND), U1.36 (GND), U1.77 (GND), U2.3 (GND), U2.8 (GND), U3.2 (GND), U4.4 (GND), U5.1 (GND), X1.2 (GND), X1.4 (GND)
unnamed: C15.2, J1.SH (SHIELD), R59.1
unnamed: LED1.2 (A), R70.2
unnamed: LED1.1 (K), Q2.3 (D)
unnamed: LED2.2 (A), R71.2
unnamed: LED2.1 (K), Q3.3 (D)
unnamed: LED3.2 (A), R73.2
unnamed: LED3.1 (K), Q4.3 (D)
unnamed: LED4.2 (A), R75.2
unnamed: LED4.1 (K), Q5.3 (D)
unnamed: Q6.3 (D), R82.2, U4.1 (EN)
unnamed: R77.1, R78.2, SW1.1
unnamed: R79.2, R80.1, SW2.1
unnamed: C25.2, FB2.1, U1.2 (AVDD)
unnamed: C5.2, C21.2, C22.2, C23.2, C24.2, FB2.2, U1.3 (VD10), U1.30 (VD10), U1.33 (VD10), U1.39 (DV10), U1.48 (VD10)
unnamed: R1.1, U1.27 (RREF)
unnamed: C3.2, U1.21 (XI), X1.3
unnamed: C4.2, U1.22 (XO), X1.1
unnamed: C73.2, R60.1, R61.2, U4.3 (FB)
unnamed: L1.1, U4.5 (SW)
unnamed: C76.1, R62.2, U5.7 (VREF2), U5.8 (EN)
VBUS: FB1.1, J1.1 (VBUS), U3.5 (VBUS)
VCC: C7.2, C16.2, C17.2, C18.2, C74.1, J3.24, J3.26, J3.29, J3.31, J4.2, J4.4, R2.1, R52.2, R53.2, R54.2, R63.1, R64.1, R68.1, SW1.2, SW2.2, SW3.1, SW3.2, U1.14 (VCCIO), U1.49 (VCCIO), U1.59 (VCCIO), U1.68 (VCCIO), U5.2 (VREF1)

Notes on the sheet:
GCLK
BANK7
BANK4
BANK7
VFB=0.6V
BANK6
RPLL
BANK2
3.3V
BANK0
Tang Primer 25K(GW5A-25K-MG121N)
BANK10
MIPI
BANK1
BANK5
BANK3
RPLL

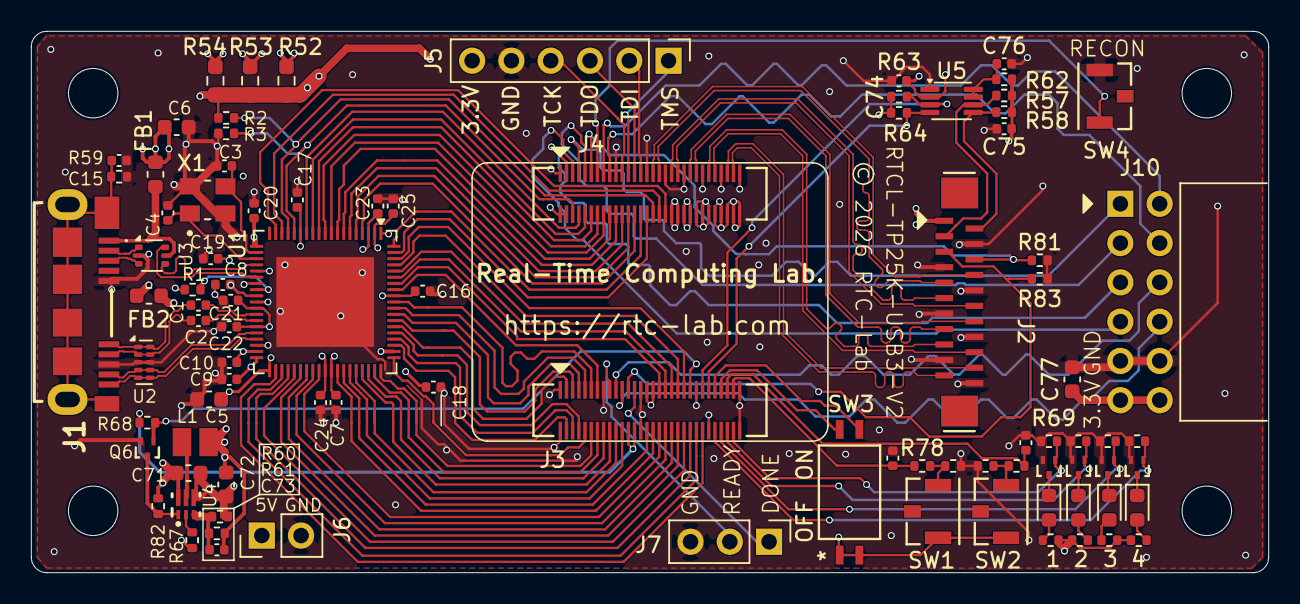
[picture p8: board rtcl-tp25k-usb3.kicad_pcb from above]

Board: 4 copper layers, 80.0 x 35.0 mm, 91 parts (0 on the bottom side), 126 nets.

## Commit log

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2026-05-08 Add new footprints for RES_YC104_YAG and RES_YC164_3P2X1P6_YAG
    - Created footprint for RES_YC104_YAG with detailed properties and pads.
    - Created footprint for RES_YC164_3P2X1P6_YAG with comprehensive design elements and specifications.
    [rtcl-p25k-usb3.kicad_pcb, rtcl-p25k-usb3.kicad_sch]
2026-05-08 Add FT601Q symbol to KiCad library
    - Created a new symbol for the FT601Q USB 3.0 FIFO interface IC.
    - Included properties such as Reference, Value, Footprint, Datasheet, and Description.
    - Defined 77 pins with appropriate names, types, and attributes.
    - Ensured compatibility with KiCad version 10.0 and included necessary font settings.
    [rtcl-p25k-usb3.kicad_pcb, rtcl-p25k-usb3.kicad_sch]
2026-05-08 Update KiCad project files for rtcl-p25k-usb3
    - Changed active layer from 25 to 5 in the project file.
    - Updated footprint property for components in the schematic:
    - Changed footprint for a connector to "rtcl-p25k-usb3:CON_525592253_MOL".
    - Updated value for a component from "BTB-DF40C-60DS-0.4V(51)" to "DF40C-60DS-0.4V(51)".
    - Changed footprint for another component to "rtcl-p25k-usb3:PMOD_02x06_2.54mm".
    - Modified UUIDs for various graphical elements in the CONN_DF40C-60DS_HIR module.
    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
    [rtcl-p25k-usb3.kicad_pcb, rtcl-p25k-usb3.kicad_sch]
2026-05-09 Update model paths in KiCad module files for consistency
    - Changed model path for CONN10_ZX360D-B-10P30_HIR.kicad_mod to reflect the correct directory structure.
    - Updated model path for CONN_DF40C-60DS_HIR.kicad_mod to point to the new location.
    - Modified model path for CON_525592253_MOL.kicad_mod to ensure it aligns with the updated project directory.
    [rtcl-tp25k-usb3.kicad_pcb, rtcl-tp25k-usb3.kicad_sch]
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2026-05-10 Update project settings and parameters
    - Modified selection filter settings in the .kicad_prl file to disable footprint and locked items selection.
    - Added a new parameter value (0.12954) to the list in the .kicad_pro file for improved configuration.
    [rtcl-tp25k-usb3.kicad_pcb]
2026-05-10 Add PCB statistics report for rtcl-tp25k-usb3 project
    - Include detailed dimensions, area, and component density
    - Document pad and via counts
    - Provide drill hole specifications
    [lenth_table.csv, pin_assign.csv, pin_assign.xlsx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]
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2026-05-10 Update KiCad project files and add pin assignment documentation
    - Changed selection filter for footprints in the KiCad project rules file to true.
    - Adjusted minimum clearance value in the KiCad project settings from 0.5 to 0.2.
    - Added new Excel file for pin assignments with lengths to the documentation directory.
    [pin_assign_with_lengths.xlsx, rtcl-tp25k-usb3.kicad_pcb]
2026-05-10 Update KiCad project files and component definitions
    - Changed active layer from 4 to 0 in the project settings.
    - Enabled text visibility in the board settings.
    - Adjusted clearance values for various classes in the project configuration to improve design rules.
    - Updated UUIDs for multiple elements in the component definition file to ensure uniqueness and avoid conflicts.
    - Removed redundant lines in the component definition for clarity and conciseness.
    [rtcl-tp25k-usb3.kicad_pcb]
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2026-05-10 Refactor PCB and schematic files for improved layout and component management
    - Updated active layer in the PCB design from 31 to 25 for better visibility.
    - Disabled text display in the PCB design to reduce clutter.
    - Removed unnecessary junctions and wires from the schematic to streamline the design.
    - Adjusted component placements and properties, including resistors and capacitors, for better alignment and readability.
    - Changed UUIDs for various elements in the schematic and PCB files to ensure uniqueness and prevent conflicts.
    - Updated the connector module with new UUIDs and cleaned up unnecessary geometry.
    [rtcl-tp25k-usb3.kicad_pcb, rtcl-tp25k-usb3.kicad_sch]
2026-05-11 Refactor KiCad project files for improved layout and organization
    - Updated active layer in the project file to layer 5 for better visibility.
    - Modified selection filter settings to hide dimensions, footprints, graphics, keepouts, other items, pads, tracks, vias, and zones.
    - Cleared used designators in the project file to streamline component management.
    - Adjusted junction and wire coordinates in the schematic for better alignment and clarity.
    - Renamed labels in the schematic for consistency and clarity.
    - Updated component positions and properties in the schematic to enhance layout.
    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
    [pin_assign.xlsx, rtcl-tp25k-usb3.kicad_pcb, rtcl-tp25k-usb3.kicad_sch]
2026-05-11 Update footprint and text attributes in KiCad project files for improved clarity and accuracy
    [rtcl-tp25k-usb3.kicad_pcb]
2026-05-14 Refactor KiCad project files: update active layer, toggle visibility settings, and remove unnecessary junctions and wires
    - Changed active layer from 5 to 0 in the .kicad_prl file.
    - Modified visibility settings for text, tracks, and vias in the .kicad_prl file.
    - Updated visible layers string in the .kicad_prl file.
    - Removed redundant junctions and wires from the .kicad_sch file to clean up the schematic.
    - Added new wire connections and labels for better clarity in the .kicad_sch file.
    - Adjusted positions of several labels for improved layout in the .kicad_sch file.
    [rtcl-tp25k-usb3.kicad_pcb, rtcl-tp25k-usb3.kicad_sch]
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2026-05-14 Update active layer and selection filter settings in KiCad project file
    - Changed active_layer from 6 to 0 for initial layer setup.
    - Disabled footprint selection in the filter.
    - Enabled locked items in the selection filter.
    - Disabled via selection in the filter.
    [rtcl-tp25k-usb3.kicad_pcb]
2026-05-14 Update selection filter settings in KiCad project file
    - Changed selection filter options to enable visibility for dimensions, footprints, graphics, keepouts, locked items, other items, pads, text, vias, and zones.
    - This enhances the usability of the design environment by allowing more elements to be selected and manipulated.
    [rtcl-tp25k-usb3.kicad_pcb]
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2026-05-14 Update KiCad project settings and add length table for Tang Primer 25K
    - Changed active layer from 2 to 4 in the KiCad project file.
    - Updated selection filter to enable visibility for dimensions, footprints, graphics, keepouts, other items, pads, text, vias, and zones.
    - Modified visible layers and zone display mode in the KiCad project file.
    - Added a new Excel file for the Tang Primer 25K length table in the documentation directory.
    [TangPrimer25K_Length_table_pmod.xlsm, rtcl-tp25k-usb3.kicad_pcb]
2026-05-16 Update visible_layers in rtcl-tp25k-usb3.kicad_prl to correct layer visibility settings
    [rtcl-tp25k-usb3.kicad_pcb]
2026-05-16 Fix visibility settings in KiCad project file for improved layer management
    [rtcl-tp25k-usb3.kicad_pcb]
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2026-05-21 Update BOM: correct part numbers for J10 and J5
    [bom.csv]
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2026-05-22 発注時にWebで直した部分など修正
    [rtcl-tp25k-usb3.kicad_pcb, rtcl-tp25k-usb3.kicad_sch]
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2026-06-28 SW3を回転させシルクを修正
    [pin_assign.xlsx, rtcl-tp25k-usb3.kicad_pcb, rtcl-tp25k-usb3.kicad_sch]
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

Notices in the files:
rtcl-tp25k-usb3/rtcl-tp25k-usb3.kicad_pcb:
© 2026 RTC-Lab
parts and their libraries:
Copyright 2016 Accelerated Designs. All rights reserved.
